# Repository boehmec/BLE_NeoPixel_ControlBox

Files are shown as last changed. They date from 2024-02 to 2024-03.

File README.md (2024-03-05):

### This is a small project for underground LED for my electric mountainboard.

See https://github.com/boehmec/esk8-remote-sender

Use e.g. NRF connect on your phone to send the commands to the published BLE service.
Search for the device with name "BLE NeoPixel Board Control". Connect.

You can use it also for other stuff.

## VSCode vs Arduino

I startetd coding with Arduino IDE but found it to be very cumbersome the bigger the projects get. Thats why I switch more and more projects I make over to VSCode.

## 3D files to print

I designed a simple box to hold all electronics, like ESP32-C3, a LiIon Charger, the LiIon Holder with LiIon (18650) and a 5V step up converter for the NeoPixel LEDs.
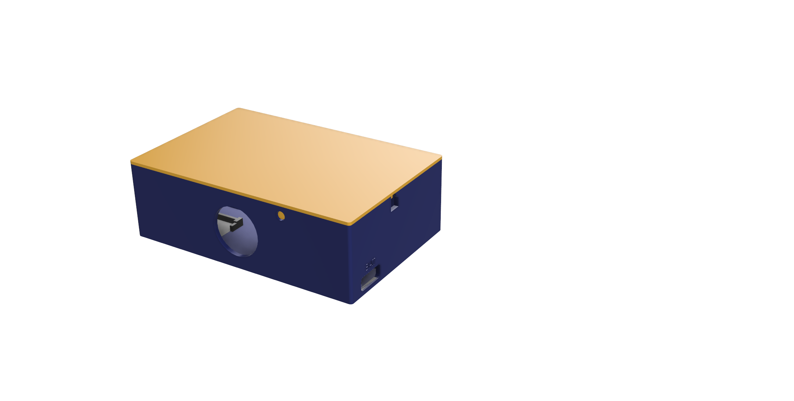
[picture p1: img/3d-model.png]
3D Model


## Commands: 0-9

You can send 10 different commands to the control box, see below:

- 0: turn color to red
- 1: turn color to green
- 2: turn color to blue
- 3: start pulsing current color, and make pulsing also faster
- 4: start pulsing current color, and make pulsing also slower
- 5: current brightness darker
- 6: current brightness brighter
- 7: max brightness darker
- 8: max brightness brighter
- 9: reset to default

## LIVE Mode

There is a BLE Characteristic you can write to that accepts integer values 0 - 255 for brightness control.
0 effectively turns the LEDs completely off.
This can be useful for e.g. throttle/ brake animation or sound control.

See here https://github.com/boehmec/esk8-remote-sender/blob/f7f75f4035cb45c6e086482c0af7b64ef2a55e34/include/LEDControlHandler.h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
for an implementation.

## Schematic

    +------------------------+
    |        Step-up         |
    |      Converter         |
    |                        |
    |   Vin ---- Power Switch| (Voltage from LiPo)
    |   Vout ---+------> LED Strip (5V)/ ESP32 5V
    |   GND ---- GND          |
    +------------------------+
           |
           |  +--------------+
           |  |   ESP32-C3   |
           |  +--------------+
           |      |     |
           |      |     +----> Pin 4 ----> LED Strip
           |      |
           |      +----> Pin 5 ----> Power Switch LED (Positive)
           |      |
           |      +----> Pin 6 ----> Power Switch LED GND (Negative)
           |      |
           |      +----> +5V   ----> Step-up Converter (+5V)
           |      |
           |      +----> GND   ----> Step-up Converter (GND)
           |
           +------------------------+
                   |
                   |
    +--------------|-------------+
    |  LiPo Charger Circuit      |
    |                            |
    |  +----> Battery (+)        |
    |  |                         |
    |  +----> Battery (-)        |
    |  |                         |
    |  +----> Vout ----> Power Switch (Normally Closed)
    |  |                         |
    |  +----> GND                 |
    +-----------------------------+

## BOM

| Component  | Link |
| --- | --- |
| ESP32-C3  | https://de.aliexpress.com/item/1005006170575141.html |
| 5V Mini-Step-Up-Boost | https://de.aliexpress.com/item/1005006144998899.html  |
| LiPo Charger Circuit | https://de.aliexpress.com/item/1005005865606098.html |
| LiIon Holder | https://de.aliexpress.com/item/32825161070.html |
| Power Switch Self Locking 16mm| https://de.aliexpress.com/item/1005002509687799.html |

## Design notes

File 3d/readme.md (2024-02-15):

## Print instructions

the btm part prints in ~ 1h:30m
  
the top part prints in ~ 0h:45m

### print settings
layer height: 0.2

print speed: 50mm/s walls: 40mm/s

temp: 190°

fan: 100%

support: no

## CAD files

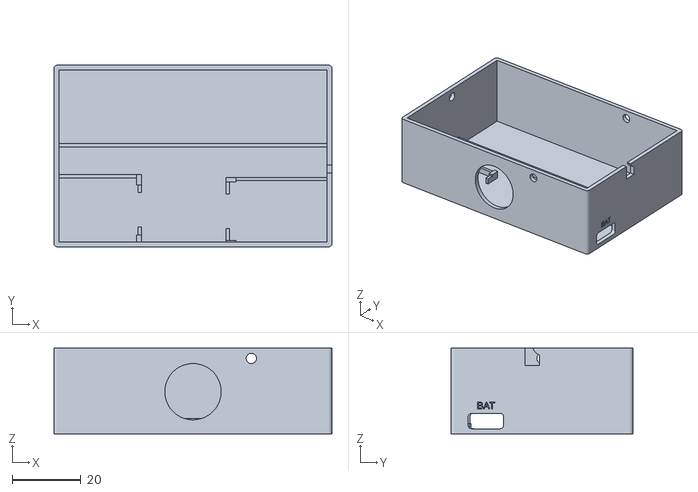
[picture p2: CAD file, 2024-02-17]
3d/led-control-box.stl
81.0 x 53.0 x 25.0

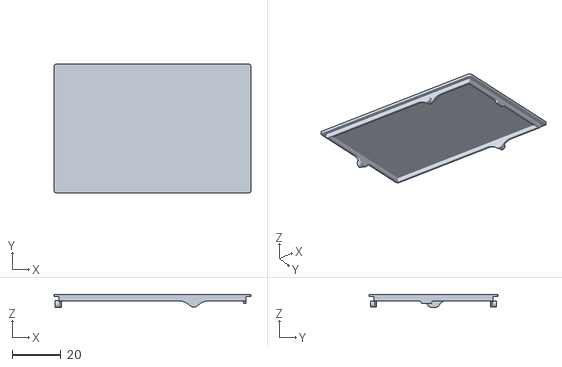
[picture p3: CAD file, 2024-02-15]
3d/top.stl
81.0 x 53.0 x 5.50

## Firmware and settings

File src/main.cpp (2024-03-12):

#include <Adafruit_NeoPixel.h>
#include <BLEDevice.h>
#include <BLEServer.h>
#include <BLEUtils.h>
#include <BlockNot.h>
#include <ArduinoJson.h>

/**
  General Commands: 0-9
  0: turn color to red
  1: turn color to green
  2: turn color to blue
  3: start pulsing current color, and make pulsing also faster
  4: start pulsing current color, and make pulsing also slower
  5: current brightness darker
  6: current brightness brighter
  7: max brightness darker
  8: max brightness brighter
  9: reset to default

  Live brightness:
  - send a value 0-255 to LIVE_BRIGHTNESS_CHARACTERISTIC_UUID (sanity checks like maxBrightness apply)
  - this can easily get expanded to sound control feature
*/
#define LEDS 30
#define PIN 4
// our power switch has an onboard LED we can power with our ESP alone
#define BTN_VCC_PIN 5
#define BTN_GND_PIN 6
#define SERVICE_UUID "68a3891c-3667-4937-b89b-f69479854ae7"
#define COMMAND_CHARACTERISTIC_UUID "284c702d-3609-4939-bd2a-7f88a7d383f8"
#define LIVE_BRIGHTNESS_CHARACTERISTIC_UUID "39cdb833-ad1b-442f-8845-715d69e27614"
#define COLOR_CHARACTERISTIC_UUID "0c092dce-abcf-4681-b649-cbbeb7cff702"

#define DEFAULT_MAX_BRIGHTNESS 90
#define DEFAULT_PULSE_DURATION 40
#define MAX_COMMAND_NR 10
const int MAX_MTU = 350;

Adafruit_NeoPixel strip(LEDS, PIN, NEO_GRB + NEO_KHZ800);

BLEServer *pServer = NULL;
BLECharacteristic *commandsCharacteristic = NULL;
BLECharacteristic *liveBrightnessCharacteristic = NULL;
BLECharacteristic *colorCharacteristic = NULL;
bool deviceConnected = false;
bool oldDeviceConnected = false;

// will save energy, our 5V buck boost can handle only 0.8Amps and if 255 would
// be max = 1.8Amps then 100 ~ 0.7A increase at own risk
int maxBrightness = DEFAULT_MAX_BRIGHTNESS;
int brightness = DEFAULT_MAX_BRIGHTNESS;
bool turnBrightnessUp = true;
int currentPulseDuration = DEFAULT_PULSE_DURATION;

BlockNot bleTimer = BlockNot(1500, STOPPED);
// default 50 can be changed using commands
BlockNot pulseTimer(currentPulseDuration, STOPPED); 

// from default examples, just sets new color for each led
void colorWipe(uint32_t color, int wait) {
  for (int i = 0; i < strip.numPixels(); i++) {
    strip.setPixelColor(i, color);
    strip.show();
    delay(wait);
  }
}

//works only when using either R G B as 255 int, not lower values
void enablePulse(int duration) {
log_i("Set pulse duration %d", duration);
  pulseTimer.setDuration(duration);
  if (pulseTimer.isStopped()) {
    pulseTimer.START_RESET;
  }
}

class BLEServerCallback : public BLEServerCallbacks {
  void onConnect(BLEServer *pServer, esp_ble_gatts_cb_param_t *param) {
    log_i("Connected %d", pServer->getConnId());
    // prepare for updating params
    esp_bd_addr_t clientAddress;
    memcpy(clientAddress, param->connect.remote_bda, ESP_BD_ADDR_LEN);
    esp_gatt_conn_params_t gattConnParams = param->connect.conn_params;
    log_d("gattConnParams timeout %d interval %d latency %d",
          gattConnParams.timeout, gattConnParams.interval,
          gattConnParams.latency);
    esp_gap_conn_params_t connParams;
    ////supervision_tout  Range: 0x000A to 0x0C80 Time = N * 10 msec Time Range:
    ///100 msec to 32 seconds
    esp_ble_get_current_conn_params(clientAddress, &connParams);
    log_d("connParams timeout %d interval %d latency %d", connParams.timeout,
          connParams.interval, connParams.latency);

    esp_ble_conn_update_params_t updatedConnParams;
    memcpy(updatedConnParams.bda, clientAddress, ESP_BD_ADDR_LEN);
    // updatedConnParams.bda = clientAddress;
    updatedConnParams.min_int = 0x06; // x 1.25ms
    updatedConnParams.max_int = 0x20; // x 1.25ms
    updatedConnParams.latency = 0x00; // number of skippable connection events
    updatedConnParams.timeout =
        0x00C8; // x 200ms x 10ms = 2000ms time before peripheral will assume
                // connection is dropped.

    esp_err_t updateRes = esp_ble_gap_update_conn_params(&updatedConnParams);
    log_d("connParams updateRes %d", updateRes);
    esp_ble_get_current_conn_params(
        clientAddress,
        &connParams); ////supervision_tout  Range: 0x000A to 0x0C80 Time = N *
                      ///10 msec Time Range: 100 msec to 32 seconds
    log_d("connParams timeout %d interval %d latency %d", connParams.timeout,
          connParams.interval, connParams.latency);

    pulseTimer.STOP;
    deviceConnected = true;
    brightness = DEFAULT_MAX_BRIGHTNESS;
    colorWipe(strip.Color(0, 255, 0), 20); //green
  }

  void onDisconnect(BLEServer *pServer) {
    log_i("Disconnected %d", pServer->getConnId());
    deviceConnected = false;
    pulseTimer.STOP;
    bleTimer.START_RESET;
    strip.setBrightness(DEFAULT_MAX_BRIGHTNESS);
    colorWipe(strip.Color(255, 0, 0), 20); //red
    enablePulse(DEFAULT_PULSE_DURATION); // set pulse
  }
};

class CommandsCallback : public BLECharacteristicCallbacks {

  void onWrite(BLECharacteristic *pCharacteristic) {
    uint8_t *data = pCharacteristic->getData();
    int command = *data;
    if (command < 0 || command > MAX_COMMAND_NR) {
      log_w("Unknown command!");
      return;
    }
    log_d("Command %d", command);

    switch (command) {
    case 0:
      colorWipe(strip.Color(255, 0, 0), 0); // Red
      break;
    case 1:
      colorWipe(strip.Color(0, 255, 0), 0); // Green
      break;
    case 2:
      colorWipe(strip.Color(0, 0, 255), 0); // Blue
      break;
    case 3: // make pulse faster
      currentPulseDuration -= 10;
      if (currentPulseDuration <= 10) {
        currentPulseDuration = 10;
      }
      enablePulse(currentPulseDuration);
      break;
    case 4: // make pulse slower
      currentPulseDuration += 10;
      if (currentPulseDuration >= 100) {
        currentPulseDuration = 100;
      }
      enablePulse(currentPulseDuration);
      break;
    case 5: // current brightness darker
      brightness -= 20;
      if (brightness <= 0) {
        brightness = 0;
      }
      strip.setBrightness(brightness); // 0 ..255
      strip.show();                    // Update strip with new contents
      break;
    case 6: // current brightness brighter
      brightness += 20;
      if (brightness >= maxBrightness) {
        brightness = maxBrightness;
      }
      strip.setBrightness(brightness); // 0 ..255
      strip.show();                    // Update strip with new contents
      break;
    case 7: // max brightness darker
      maxBrightness -= 20;
      if (maxBrightness <= 1) {
        maxBrightness = 1;
      }
      break;
    case 8: // max brightness brighter
      maxBrightness += 20;
      if (maxBrightness >= 255) {
        maxBrightness = 255;
      }
      break;
    case 9: // reset to default
      // stop all pulse
      pulseTimer.STOP;
      maxBrightness = DEFAULT_MAX_BRIGHTNESS;
      brightness = DEFAULT_MAX_BRIGHTNESS;
      currentPulseDuration = DEFAULT_PULSE_DURATION;
      strip.show();
      break;
    }
  }
};

class LiveBrightnessCallback : public BLECharacteristicCallbacks {

  void onWrite(BLECharacteristic *pCharacteristic) {
    //switch off pulse timer in live mode
    if(pulseTimer.isRunning()){
      pulseTimer.STOP;
    }
    uint8_t *data = pCharacteristic->getData();
    int brightness = *data;
    // we allow a 0 brightness, effectively turning it off
    // as the client can control the color
    int adjustedBrightness = map(brightness, 0, 255, 0, maxBrightness);
    // handle small brightness edge case when we have e.g. a maxBrightness of
    // 100 and we want to display 1b then adjustedBrightness would still be 0
    // const long rise = out_max - out_min;  => 100 - 0 = 100
    // const long delta = x - in_min;        => 1 - 0   = 1
    // return (delta * rise) / run + out_min; => 1 * 100 / (255 - 0) + 0 =>
    // 100/255 = 0 (long)
    if (brightness > 0 && adjustedBrightness == 0) {
      adjustedBrightness = 1;
    }
    log_d("brightness %d -> adjustedBrightness %d", brightness, adjustedBrightness);
    strip.setBrightness(adjustedBrightness);
    strip.show();
  }
};

class ColorCallback : public BLECharacteristicCallbacks {

  void onWrite(BLECharacteristic *pCharacteristic) {
    std::string json = pCharacteristic->getValue();
     JsonDocument jsonDoc;
    DeserializationError error = deserializeJson(jsonDoc, json);
    // Test if parsing succeeds.
    if (error) {
      log_e("DeserializeJson() failed: %s - \njson %s", error.f_str()), json.c_str();
      return;
    }

    int red = jsonDoc["r"];
    int green = jsonDoc["g"];
    int blue = jsonDoc["b"];
    log_i("Change color to R %d G %d B %d", red, green, blue);
    colorWipe(strip.Color(red, green, blue), 0); //no delay
  }

};

void setup() {
  log_i("BLE NeoPixel LED Box Controller");
  BLEDevice::init("BLE NeoPixel Board Control");
  BLEDevice::setMTU(MAX_MTU);
  esp_ble_tx_power_set(ESP_BLE_PWR_TYPE_DEFAULT, ESP_PWR_LVL_P9);
  esp_ble_tx_power_set(ESP_BLE_PWR_TYPE_ADV, ESP_PWR_LVL_P9);
  esp_ble_tx_power_set(ESP_BLE_PWR_TYPE_SCAN, ESP_PWR_LVL_P9);

  int pwrAdv = esp_ble_tx_power_get(ESP_BLE_PWR_TYPE_ADV);
  int pwrScan = esp_ble_tx_power_get(ESP_BLE_PWR_TYPE_SCAN);
  int pwrDef = esp_ble_tx_power_get(ESP_BLE_PWR_TYPE_DEFAULT);
  log_i("BLE Power is set pwrAdv %d pwrScan %d pwrDef %d", pwrAdv, pwrScan,
        pwrDef); // BLE Power is set pwrAdv 7 pwrScan 7 pwrDef 7 is highest

  pServer = BLEDevice::createServer();
  pServer->setCallbacks(new BLEServerCallback());
  BLEService *pService = pServer->createService(SERVICE_UUID);
  commandsCharacteristic = pService->createCharacteristic(COMMAND_CHARACTERISTIC_UUID, BLECharacteristic::PROPERTY_WRITE);
  commandsCharacteristic->setCallbacks(new CommandsCallback());

  liveBrightnessCharacteristic = pService->createCharacteristic(LIVE_BRIGHTNESS_CHARACTERISTIC_UUID, BLECharacteristic::PROPERTY_WRITE);
  liveBrightnessCharacteristic->setCallbacks(new LiveBrightnessCallback());

  
  colorCharacteristic = pService->createCharacteristic(COLOR_CHARACTERISTIC_UUID, BLECharacteristic::PROPERTY_WRITE);
  colorCharacteristic->setCallbacks(new ColorCallback());


  pService->start();

  BLEAdvertising *pAdvertising = BLEDevice::getAdvertising();
  pAdvertising->addServiceUUID(SERVICE_UUID);
  pAdvertising->setScanResponse(
      true); // TRUE otherwise our remote cannot find it
  pAdvertising->setMinPreferred(0x0);
  BLEDevice::startAdvertising();

  strip.begin();
  strip.setBrightness(DEFAULT_MAX_BRIGHTNESS); // 0 ..255
  colorWipe(strip.Color(255, 0, 0), 20); //red
  enablePulse(DEFAULT_PULSE_DURATION); // set pulse
  strip.show();

  pinMode(PIN, OUTPUT);
  digitalWrite(PIN, LOW);

  // btn led light
  pinMode(BTN_VCC_PIN, OUTPUT);
  pinMode(BTN_GND_PIN, OUTPUT);
  digitalWrite(BTN_VCC_PIN, HIGH); // btn led is on when esp gets energy, so its default high
  digitalWrite(BTN_GND_PIN, LOW);
}

void handlePulsing() {
  if (pulseTimer.TRIGGERED) {
    if (turnBrightnessUp) {
      brightness++;
      if (brightness >= maxBrightness) {
        brightness = maxBrightness;
        turnBrightnessUp = false;
      }
    } else {
      brightness--;
      if (brightness <= 1) { // 0 would be off and color info is lost, so set min to 1
        brightness = 1;
        turnBrightnessUp = true;
      }
    }
    strip.setBrightness(brightness); // 0 ..255
    strip.show();                    // Update strip with new contents
  }
}

void handleClient() { 
  //add code for further client handling
}

void loop() {
  handlePulsing(); 
  if (deviceConnected) {
    handleClient();
  }

  if (!deviceConnected && oldDeviceConnected) {
    if (bleTimer.TRIGGERED) {
      bleTimer.STOP;
      bleTimer.RESET;
      pServer->startAdvertising(); // restart advertising
      log_i("start advertising");
      oldDeviceConnected = deviceConnected;
    }
  }
  if (deviceConnected && !oldDeviceConnected) {
    oldDeviceConnected = deviceConnected;
    log_i("connecting");
  }
}
